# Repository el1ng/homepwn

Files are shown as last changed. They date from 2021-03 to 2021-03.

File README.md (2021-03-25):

# Homepwn



This repo contains KiCAD projects for a breakout to help jailbreak the homepod.

There are 3 projects:
- homebreakout: This is a form fitting PCB that fits underneath the homepod and contacts the POGO pins
- homepod_usb_breakout: This is a more complex PCB that does UART to USB and provides a USB connection to the Homepod.
- homepod_usb_breakout_simple: This is a simple, through hole, PCB that provides a USB connection to the Homepod, and access to the 1.8V UART pins directly.

You will need homebreakout and either homepod_usb_breakout or homepod_usb_breakout_simple

After soldering homebreakout, verify that the POGO pins do not touch each other. It requires a bit of patience and skill to solder them straight.

(note the image above has one of the FFC connectors backwards)

# Warning

Jailbreaking your Homepod is not supported, and these design files were made from reverse engineering. While they should not cause physical damage to your Homepod assuming they are soldered correctly, you are ultimately responsible for any damage you cause.

Note that no IPSWs are available for the Homepod, and if the Jailbreak fails you will be stuck with a $250 paperweight. Proceed with caution.

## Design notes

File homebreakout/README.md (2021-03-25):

# Homepod Breakout Connector
This is a form fitting breakout for the bottom of the Homepod. The Homepod bottom connector has the following pinout:

    | NC | TX | RX | CTRL | D+ | D- | GND |
    | NC | NC | NC | GND  | NC | NC | NC  |
    
    TX = UART To Homepod (1.8V)
    RX = UART From Homepod (1.8V)
    NC = No connect

CTRL is a voltage controlled pin. It works as follows:

    | No Connect, 0V up to 1.8V | No Function               |
    | 1.8V to ~3.3V             | UART Enabled              |
    | 3.3 to 5V                 | UART Enabled, USB Enabled |

Unfortunately there does not seem to be additional functionality embedded in the CTRL or other pins. I disassembled multiple Homepods and traced the pins back to the A8 processor and PMIC to verify. There are some non populated components near where the control pin goes by that may have been present during development.

UART is 1.8V. It is most likely _not_ 3.3V compatible.

# DFU Procedure

Flip the Homepod upside down and plug it in. Really.

After it enters DFU mode flip it right side up, or it will re-enter DFU mode. @DanyL has been working on a checkra1n patch to make it not enter DFU mode.

There was a lot of fun reverse engineering to figure out how this works. Might make for a good blog post one day.

# BOM

| MFG | Part | Qty | DigiKey | Mouser |
| --- | --- | --- | --- | --- |
| FCI | SLW8S-1C7LF | 1 | 609-1935-ND | 649-SLW8S-1C7LF  |
| Harwin | P70-2100045R | 8 | 952-3134-1-ND | 855-P70-2100045R |
| Any | M2x5mm machine screws | 4 | | |

You will need an opposite side 8 pin 1mm pitch FFC cable. Such as:
Molex 15167-0236
DigiKey: WM22868-ND
Mouser: 538-15167-0236

You can also get a same side connector and solder the FCI connector reversed. I recommend getting one opposite side and one same side in case you accidentally flip one of the FFC connectors.
You will need 4 M2 machine screws. 3mm to 5mm screws work well.

# Installation

Pogo pins face down, SLW85 connector goes up. The cutouts in the PCB are to help
make sure the pogo pin alignment is correct.

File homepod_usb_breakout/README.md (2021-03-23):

# Homepod USB Breakout

This USB breakout contains both a USB and UART USB connector.

In theory the UART control extra pins can also change between USB+UART and UART only mode, however, the default configuration both UART+USB are enabled.

# BOM

| Id | Designator | Quantity | Designation | MFG | Part | DigiKey | Mouser |
| -- | --- | --- | --- | --- | --- | --- | --- |
| 1  | J101,J102 | 2 | USB_B_Micro | FCI | 10118193-0001LF  | 609-4616-1-ND | 649-10118193-0001LF  |
| 2  | U103 | 1 | TPS22948DCKR | TI | TPS22948DCKR | 595-TPS22948DCKR | 595-TPS22948DCKR |
| 3  | D101,D102,D103 | 3 | BAT48JFILM | Infineon | BAT60AE6327HTSA1 | BAT60AE6327HTSA1CT-ND | 726-BAT60AE6327HTSA1 |
| 4  | C106,C104,C105 | 3 | 100nF | Any | Eg | 311-1366-1-ND | 603-C0603MRY5V9BB104 |
| 5  | R101,R102 | 2 | 27 | Any | Eg | 311-27GRCT-ND | 603-RC0603JR-0727RL  |
| 6  | C101,C103,C107 | 3 | 1uF | Any | Eg | 3490-1550-1-ND | 81-GRM39R105K6.3 |
| 7  | C102 | 1 | 10uF | Any | Eg | 478-10766-1-ND | 581-0603ZD106KAT2A |
| 8  | R103,R104 | 2 | 10k | Any | Eg | MCT0603-10K-MDCT-ND | 594-MCT0603MD1002DP5 |
| 9  | U101 | 1 | AP2127K-1.8 | Diodes Inc | AP2127K-1.8TRG1  | AP2127K-1.8TRG1 | 621-AP2127K-1.8TRG1  |
| 10 | U102 | 1 | FT230XS | FTDI | FT230XS-R | 895-FT230XS-R | 895-FT230XS-R |
| 11 | J1 | 1 | Conn_01x08_Female | FCI | SLW8S-1C7LF | 609-1935-ND | 649-SLW8S-1C7LF |
| 12 | J2 | 1 | Conn_01x04 | Any | Eg | 732-5317-ND | 710-61300411121 |
| 13 | J3 | 1 | Conn_01x03_Male | Any | Eg | 732-5316-ND | 710-61300311121 |

Don't forget an _opposite_ sided 8pin 1mm FFC cable

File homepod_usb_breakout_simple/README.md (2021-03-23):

# Homepod USB Breakout Simple
This is a simpler version of the USB Breakout. If you do not require UART and/or you want to solder through hole components instead, make this board.
It uses a USB B connector as it is simple to solder.

If you would like to access UART, you can via the pin headers. Note that UART is 1.8V and _NOT_ 3.3V compatible.

# BOM
| MFG | Part | Qty | DigiKey | Mouser |
| --- | --- | --- | --- | --- |
| CUI | UJ2-BH-2-TH | 1 | 102-5884-ND | 490-UJ2-BH-2-TH |
| FCI | SLW8S-1C7LF | 1 | 609-1935-ND | 649-SLW8S-1C7LF |

1x5 0.1" Pin header

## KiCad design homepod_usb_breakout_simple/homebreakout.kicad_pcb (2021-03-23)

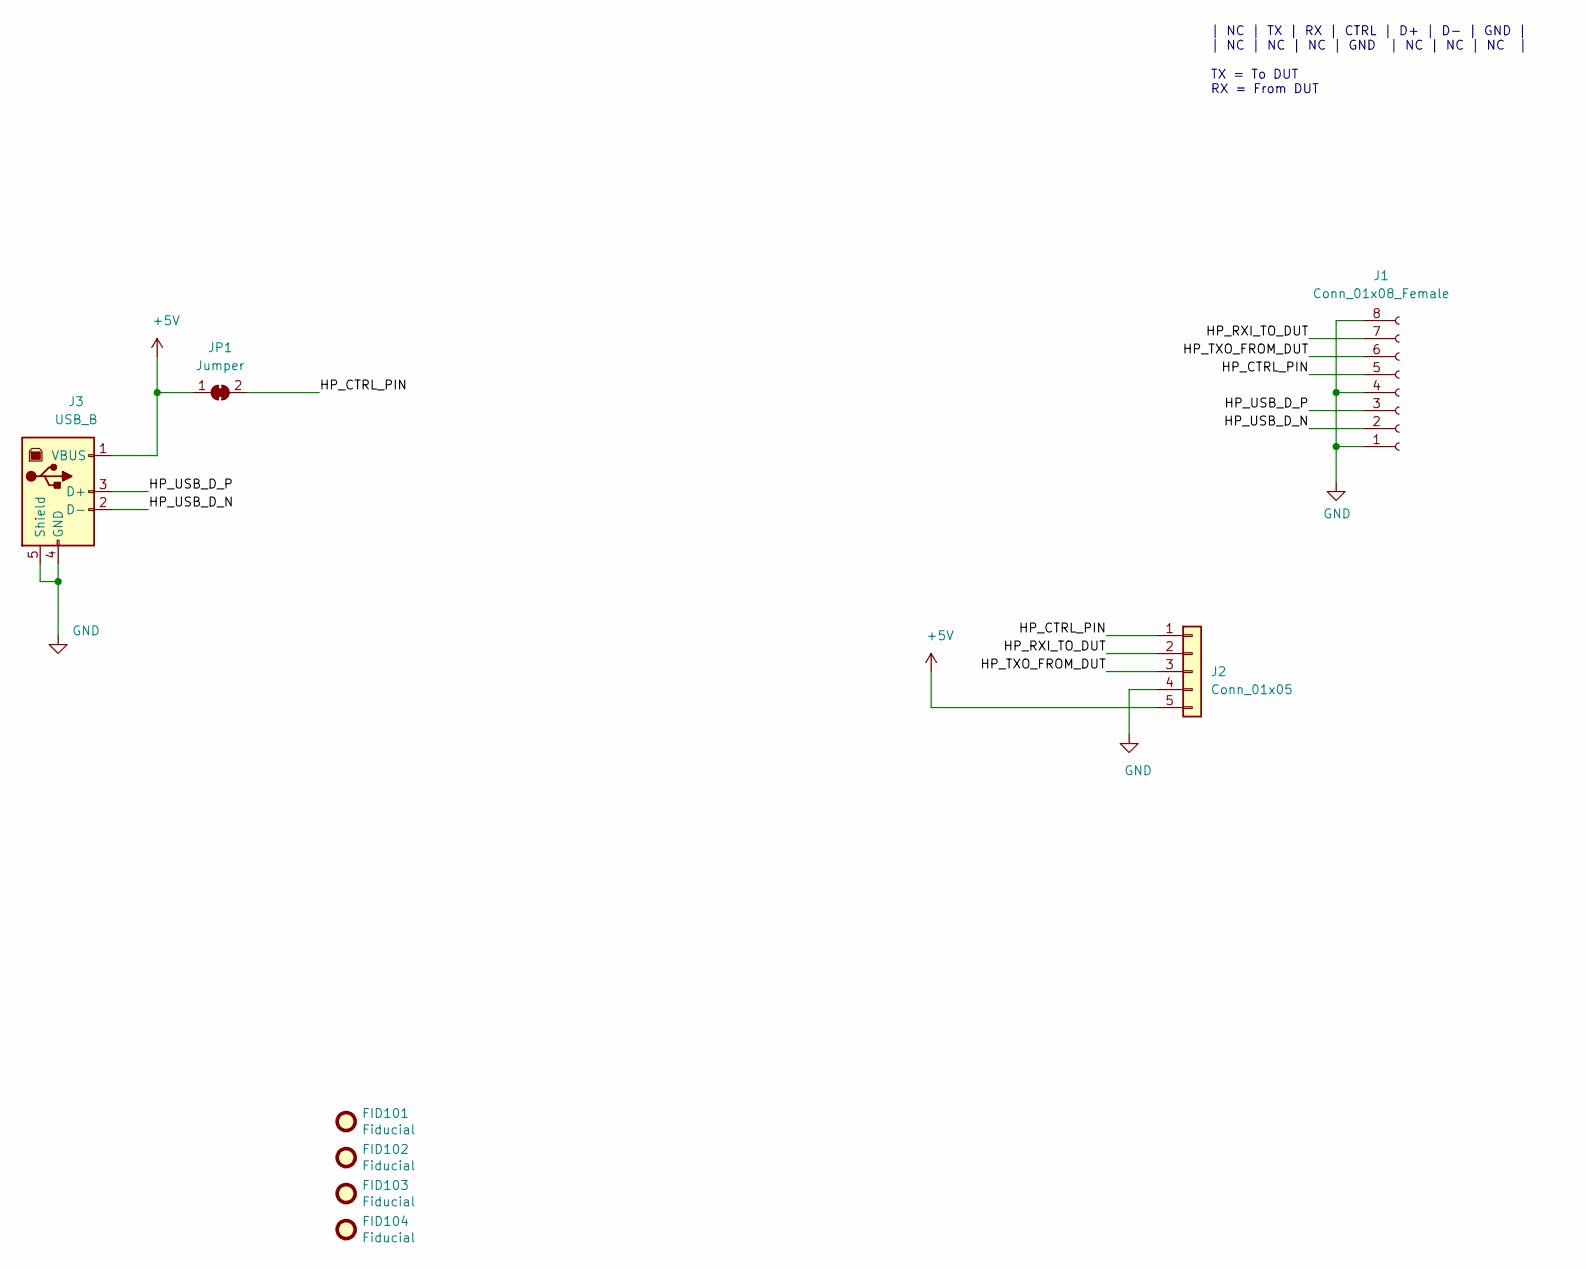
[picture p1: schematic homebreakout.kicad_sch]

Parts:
FID101, FID102, FID103, FID104: Fiducial; Fiducial_0.5mm_Dia_1mm_Outer
J1: Conn_01x08_Female; SLW8S-1C7LF
J2: Conn_01x05; PinSocket_1x05_P2.54mm_Vertical
J3: USB_B; USB_B_Lumberg_2411_02_Horizontal
JP1: Jumper; SolderJumper-2_P1.3mm_Bridged_Pad1.0x1.5mm

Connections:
+5V: J2.5, J3.1 (VBUS), JP1.1 (A)
/HP_CTRL_PIN: J1.5, J2.1, JP1.2 (B)
/HP_RXI_TO_DUT: J1.7, J2.2
/HP_TXO_FROM_DUT: J1.6, J2.3
/HP_USB_D_N: J1.2, J3.2 (D-)
/HP_USB_D_P: J1.3, J3.3 (D+)
GND: J1.1, J1.4, J1.8, J2.4, J3.4 (GND), J3.5 (Shield)

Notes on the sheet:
| NC | TX | RX | CTRL | D+ | D- | GND | | NC | NC | NC | GND | NC | NC | NC | TX = To DUT RX = From DUT

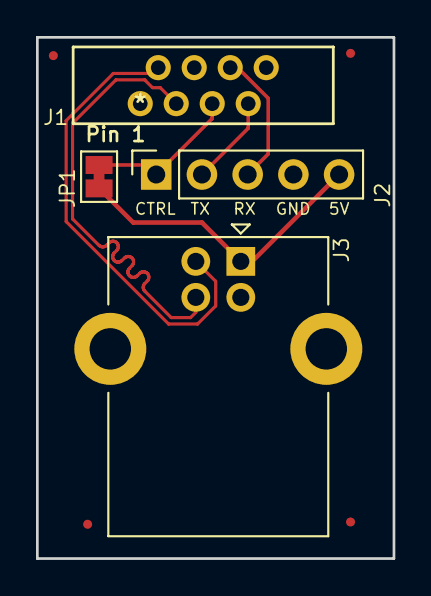
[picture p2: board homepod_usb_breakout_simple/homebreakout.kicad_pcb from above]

Board: 2 copper layers, 19.8 x 29.0 mm, 8 parts (0 on the bottom side), 7 nets.

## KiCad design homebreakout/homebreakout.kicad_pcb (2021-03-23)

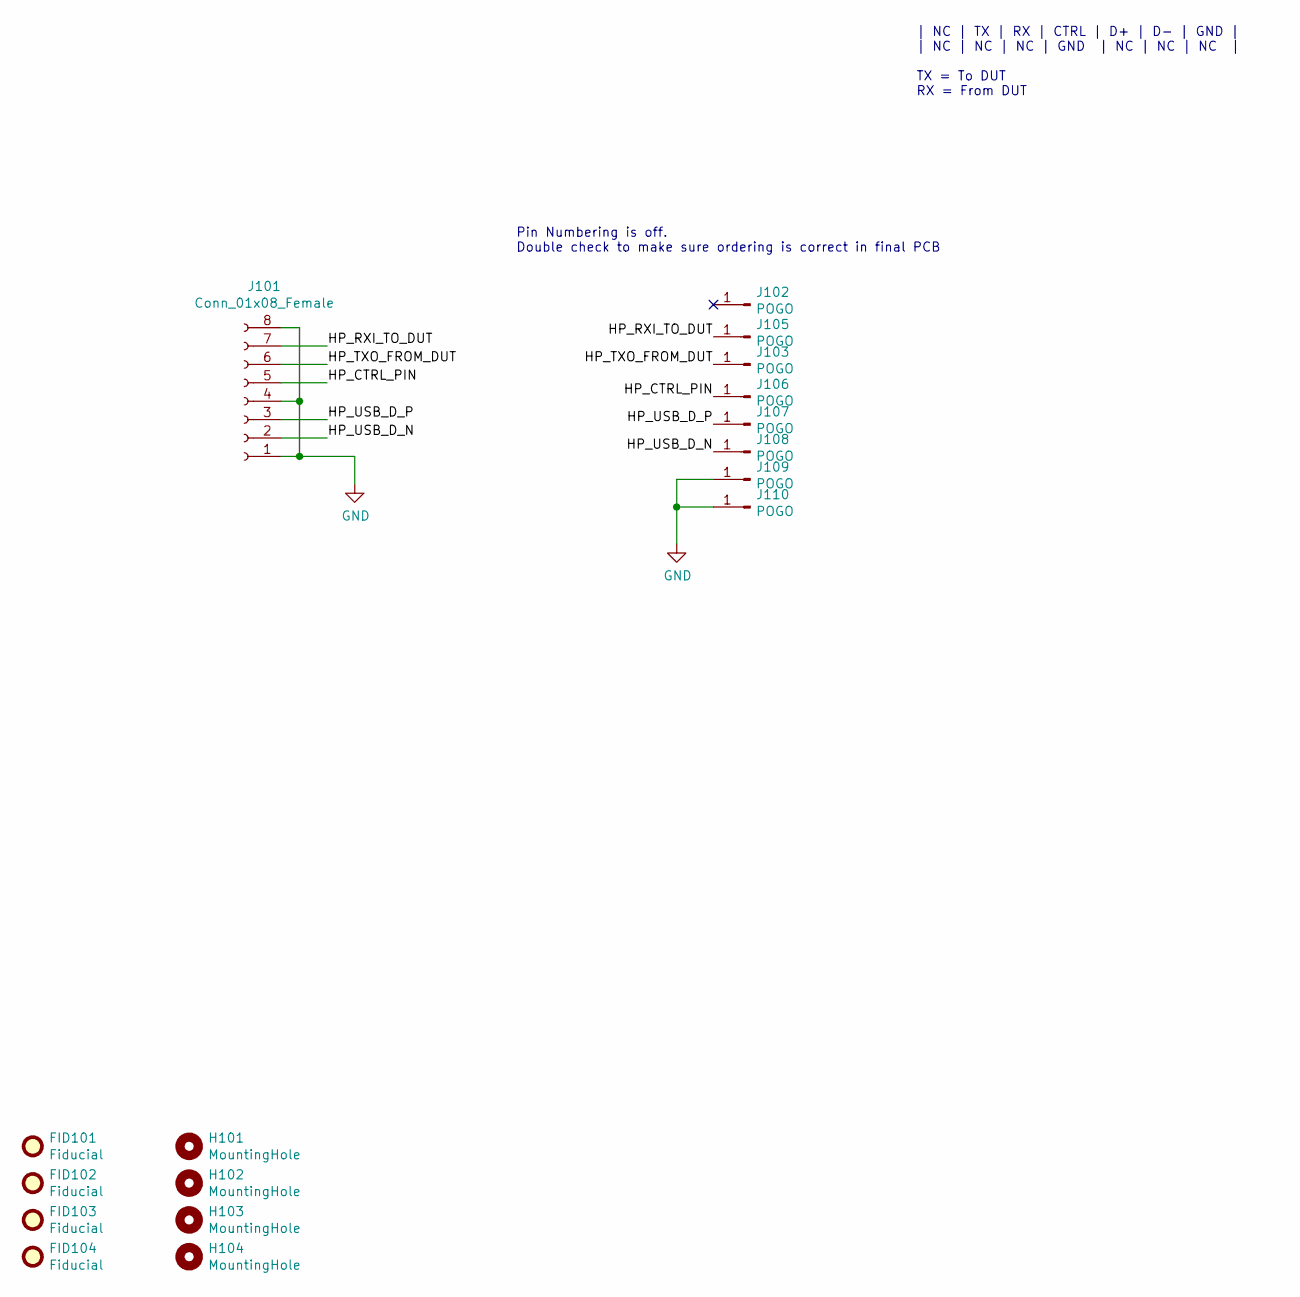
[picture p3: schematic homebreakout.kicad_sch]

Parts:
FID101, FID102, FID103, FID104: Fiducial; Fiducial_0.5mm_Dia_1mm_Outer
H101, H102, H103, H104: MountingHole; MountingHole_2.2mm_M2
J101: Conn_01x08_Female; SLW8S-1C7LF
J102, J103, J105, J106, J107, J108, J109, J110: POGO; P70_POGO

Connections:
/HP_CTRL_PIN: J101.5, J106.1
/HP_RXI_TO_DUT: J101.7, J105.1
/HP_TXO_FROM_DUT: J101.6, J103.1
/HP_USB_D_N: J101.2, J108.1
/HP_USB_D_P: J101.3, J107.1
GND: J101.1, J101.4, J101.8, J109.1, J110.1

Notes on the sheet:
Pin Numbering is off. Double check to make sure ordering is correct in final PCB
| NC | TX | RX | CTRL | D+ | D- | GND | | NC | NC | NC | GND | NC | NC | NC | TX = To DUT RX = From DUT

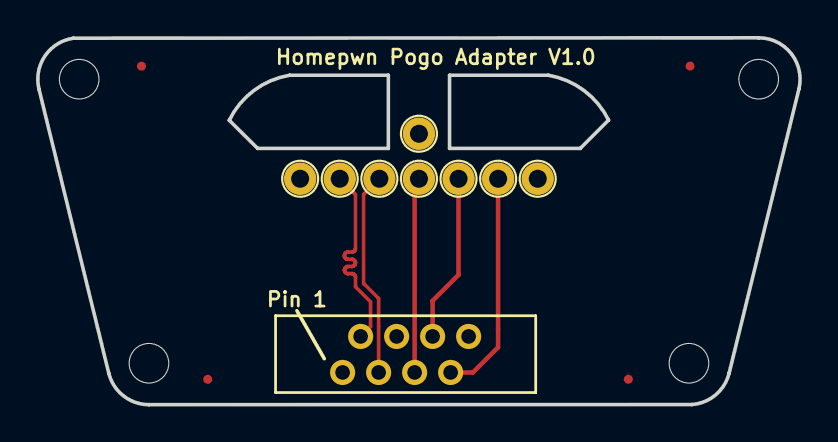
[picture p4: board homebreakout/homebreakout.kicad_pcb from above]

Board: 2 copper layers, 42.3 x 20.4 mm, 17 parts (0 on the bottom side), 6 nets.

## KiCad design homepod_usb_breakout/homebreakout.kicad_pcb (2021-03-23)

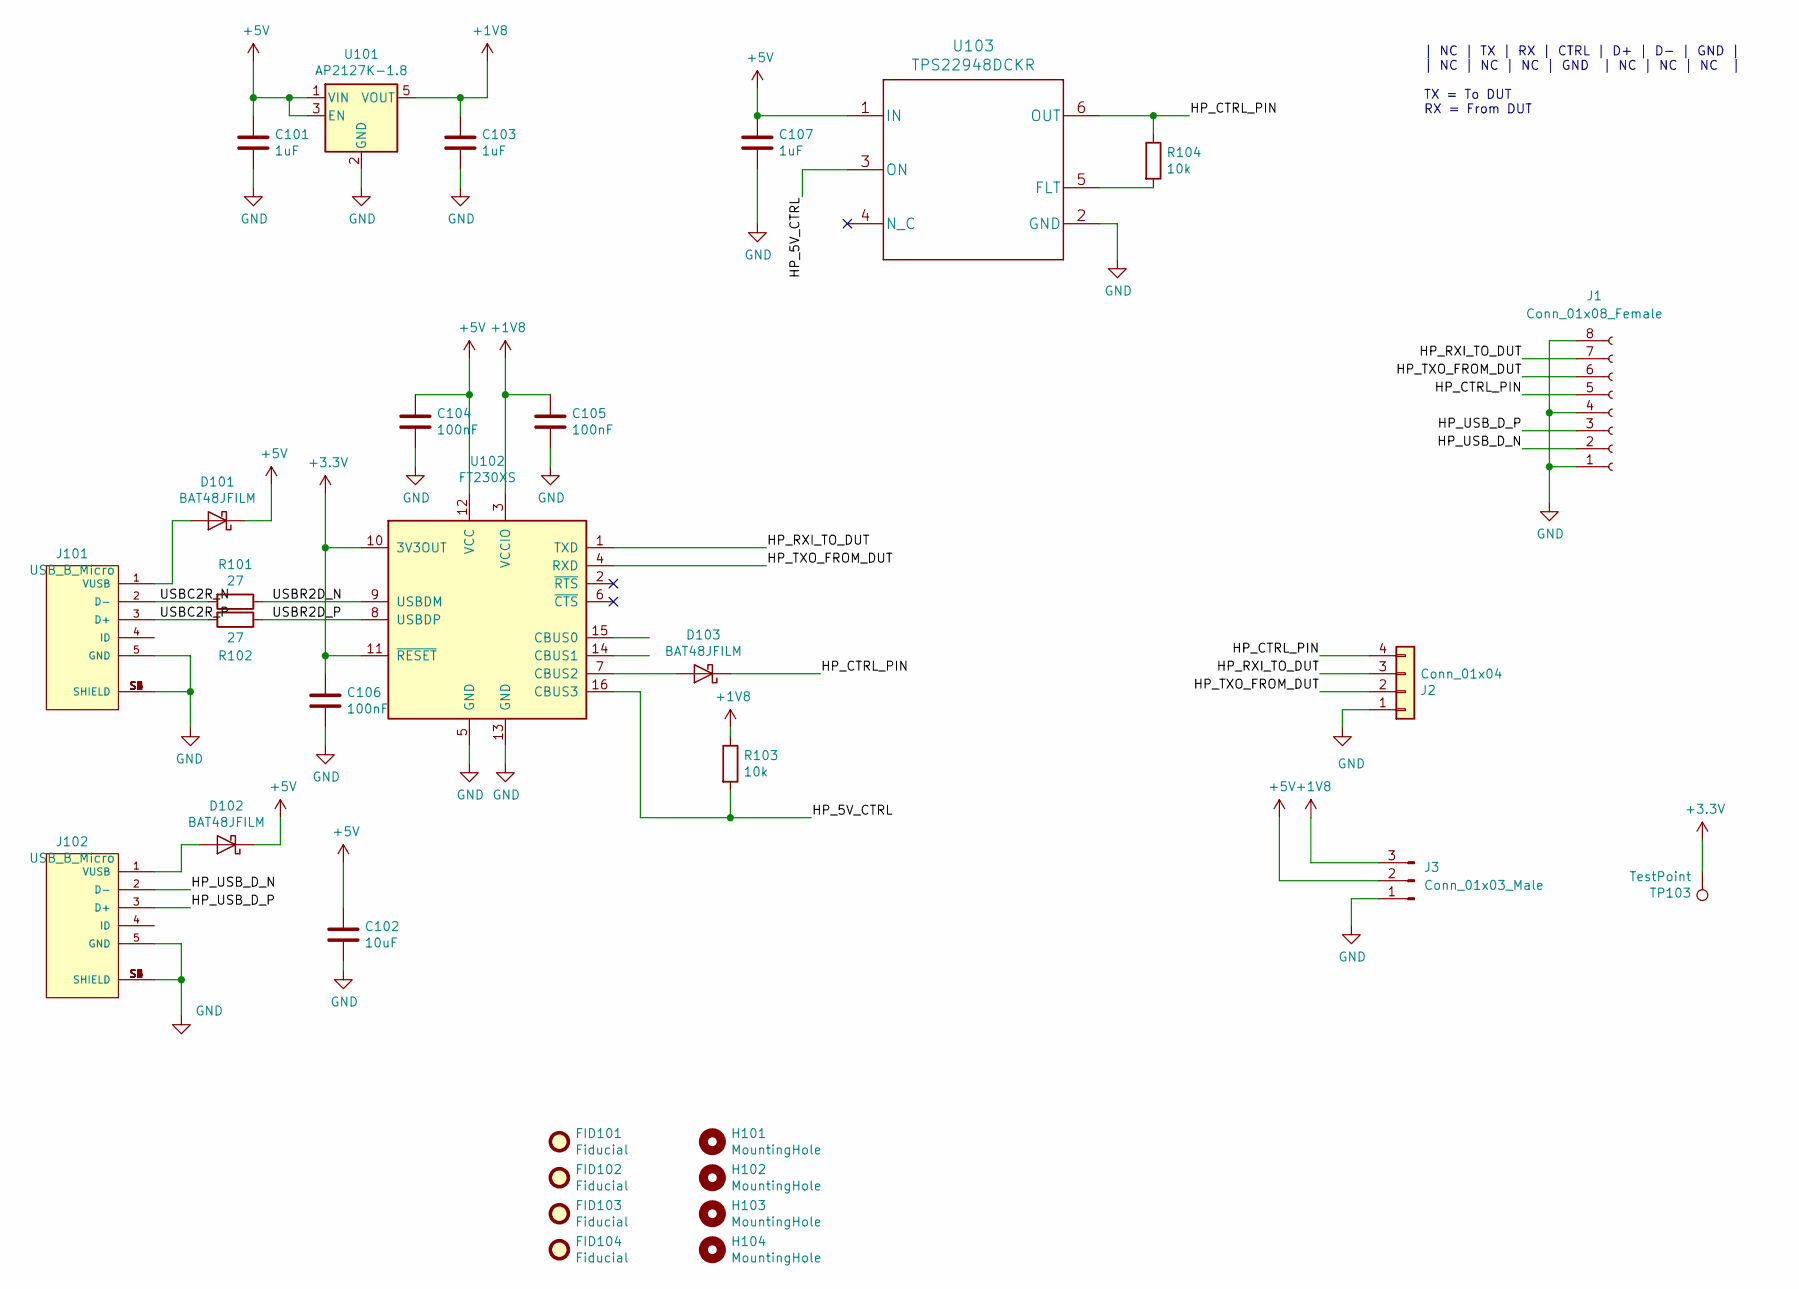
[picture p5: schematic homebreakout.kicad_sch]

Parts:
C101, C103, C107: 1uF; C_0603_1608Metric
C102: 10uF; C_0603_1608Metric
C104, C105, C106: 100nF; C_0603_1608Metric
D101, D102, D103: BAT48JFILM; D_SOD-323_HandSoldering
FID101, FID102, FID103, FID104: Fiducial; Fiducial_0.5mm_Dia_1mm_Outer
H101, H102, H103, H104: MountingHole; MountingHole_2.2mm_M2
J1: Conn_01x08_Female; SLW8S-1C7LF
J2: Conn_01x04; PinHeader_1x04_P2.54mm_Vertical
J3: Conn_01x03_Male; PinHeader_1x03_P2.54mm_Vertical
J101, J102: USB_B_Micro; FCI_10118193-0001LF
R101, R102: 27; R_0603_1608Metric
R103, R104: 10k; R_0603_1608Metric
TP103: TestPoint; TestPoint_Pad_D1.0mm
U101: AP2127K-1.8; SOT-23-5_HandSoldering
U102: FT230XS; SSOP-16_3.9x4.9mm_P0.635mm
U103: TPS22948DCKR; SOT-363_SC-70-6_Handsoldering

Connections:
+1V8: C103.1, C105.1, J3.3, R103.1, U101.5 (VOUT), U102.3 (VCCIO)
+3V3: C106.1, TP103.1, U102.10 (3V3OUT), U102.11 (~RESET)
+5V: C101.1, C102.1, C104.1, C107.1, D101.1 (K), D102.1 (K), J3.2, U101.1 (VIN), U101.3 (EN), U102.12 (VCC), U103.1 (IN)
/HP_5V_CTRL: R103.2, U102.16 (CBUS3), U103.3 (ON)
/HP_CTRL_PIN: D103.1 (K), J1.5, J2.4, R104.1, U103.6 (OUT)
/HP_RXI_TO_DUT: J1.7, J2.3, U102.1 (TXD)
/HP_TXO_FROM_DUT: J1.6, J2.2, U102.4 (RXD)
/HP_USB_D_N: J1.2, J102.2 (D-)
/HP_USB_D_P: J1.3, J102.3 (D+)
/USBC2R_N: J101.2 (D-), R101.2
/USBC2R_P: J101.3 (D+), R102.2
/USBR2D_N: R101.1, U102.9 (USBDM)
/USBR2D_P: R102.1, U102.8 (USBDP)
GND: C101.2, C102.2, C103.2, C104.2, C105.2, C106.2, C107.2, J1.1, J1.4, J1.8, J2.1, J3.1, J101.5 (GND), J101.S1 (SHIELD), J101.S2 (SHIELD), J101.S3 (SHIELD), J101.S4 (SHIELD), J101.S5 (SHIELD), J101.S6 (SHIELD), J102.5 (GND), J102.S1 (SHIELD), J102.S2 (SHIELD), J102.S3 (SHIELD), J102.S4 (SHIELD), J102.S5 (SHIELD), J102.S6 (SHIELD), U101.2 (GND), U102.5 (GND), U102.13 (GND), U103.2 (GND)
unnamed: D101.2 (A), J101.1 (VUSB)
unnamed: D102.2 (A), J102.1 (VUSB)
unnamed: D103.2 (A), U102.7 (CBUS2)
unnamed: R104.2, U103.5 (FLT)

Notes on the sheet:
| NC | TX | RX | CTRL | D+ | D- | GND | | NC | NC | NC | GND | NC | NC | NC | TX = To DUT RX = From DUT

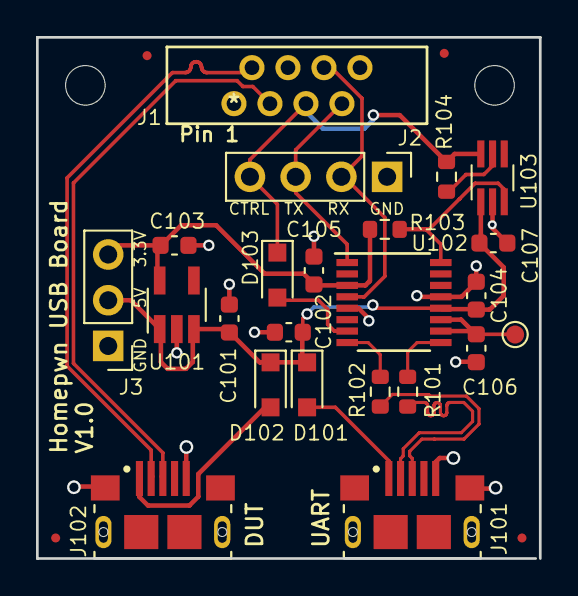
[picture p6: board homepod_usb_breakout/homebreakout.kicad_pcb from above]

Board: 2 copper layers, 27.9 x 29.0 mm, 29 parts (0 on the bottom side), 18 nets.

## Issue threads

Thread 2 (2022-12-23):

HomePod DFU firmware flash?

iRonJ, 2022-12-23:
There's a known issue with some HomePods go into a boot loop. Apple says this is a logic board failure, but the community thinks it might just be corrupt firmware.

Your thread on twitter seems to be the most successful attempt anyone has done of seeing a console/diagnostic message on what's actually wrong.

I have a working HomePod and a busted one stuck in the boot loop. Do you know if it would be possible to use the tools in this repo to dump the firmware from the good HomePod and copy it to the boot looping HomePod?
